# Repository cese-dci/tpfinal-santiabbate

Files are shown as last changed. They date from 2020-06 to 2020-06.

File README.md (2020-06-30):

# TP final de la materia Diseño de Circuitos Impresos - CESE - 2020A
## Réplica  modificada Heltec Wifi LoRA V2

Propuesta general: Eliminar el display OLED y reemplazar los circuitos integrados ESP32 y SX1278 por los módulos ESP32-WROOM y Ra-01.

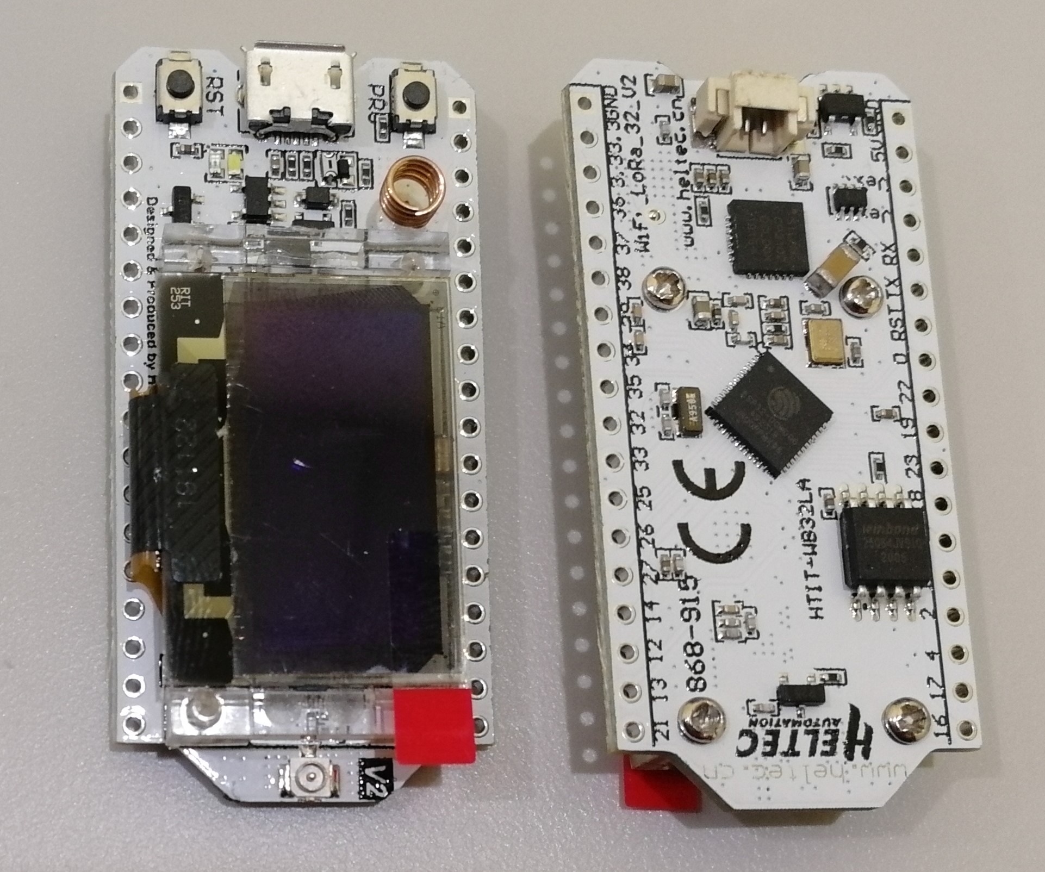
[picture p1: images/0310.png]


## Resultado

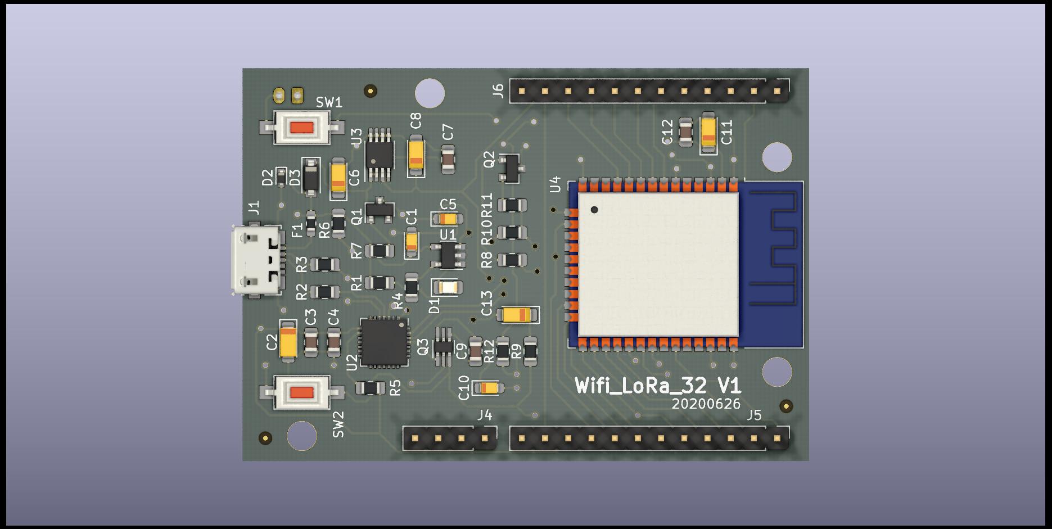
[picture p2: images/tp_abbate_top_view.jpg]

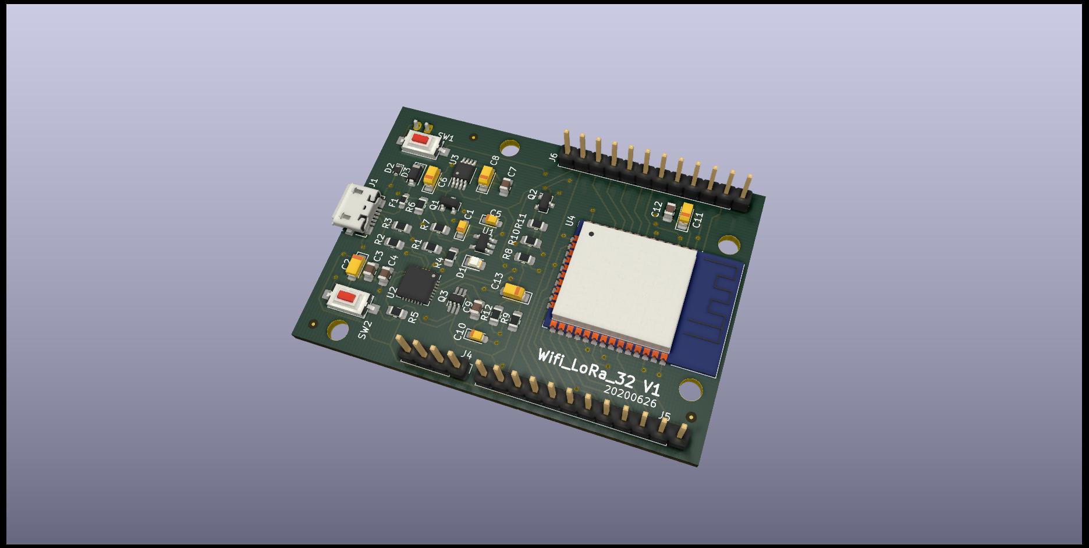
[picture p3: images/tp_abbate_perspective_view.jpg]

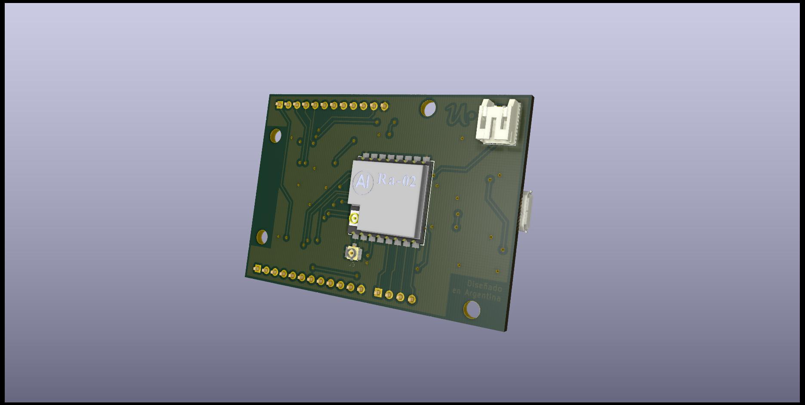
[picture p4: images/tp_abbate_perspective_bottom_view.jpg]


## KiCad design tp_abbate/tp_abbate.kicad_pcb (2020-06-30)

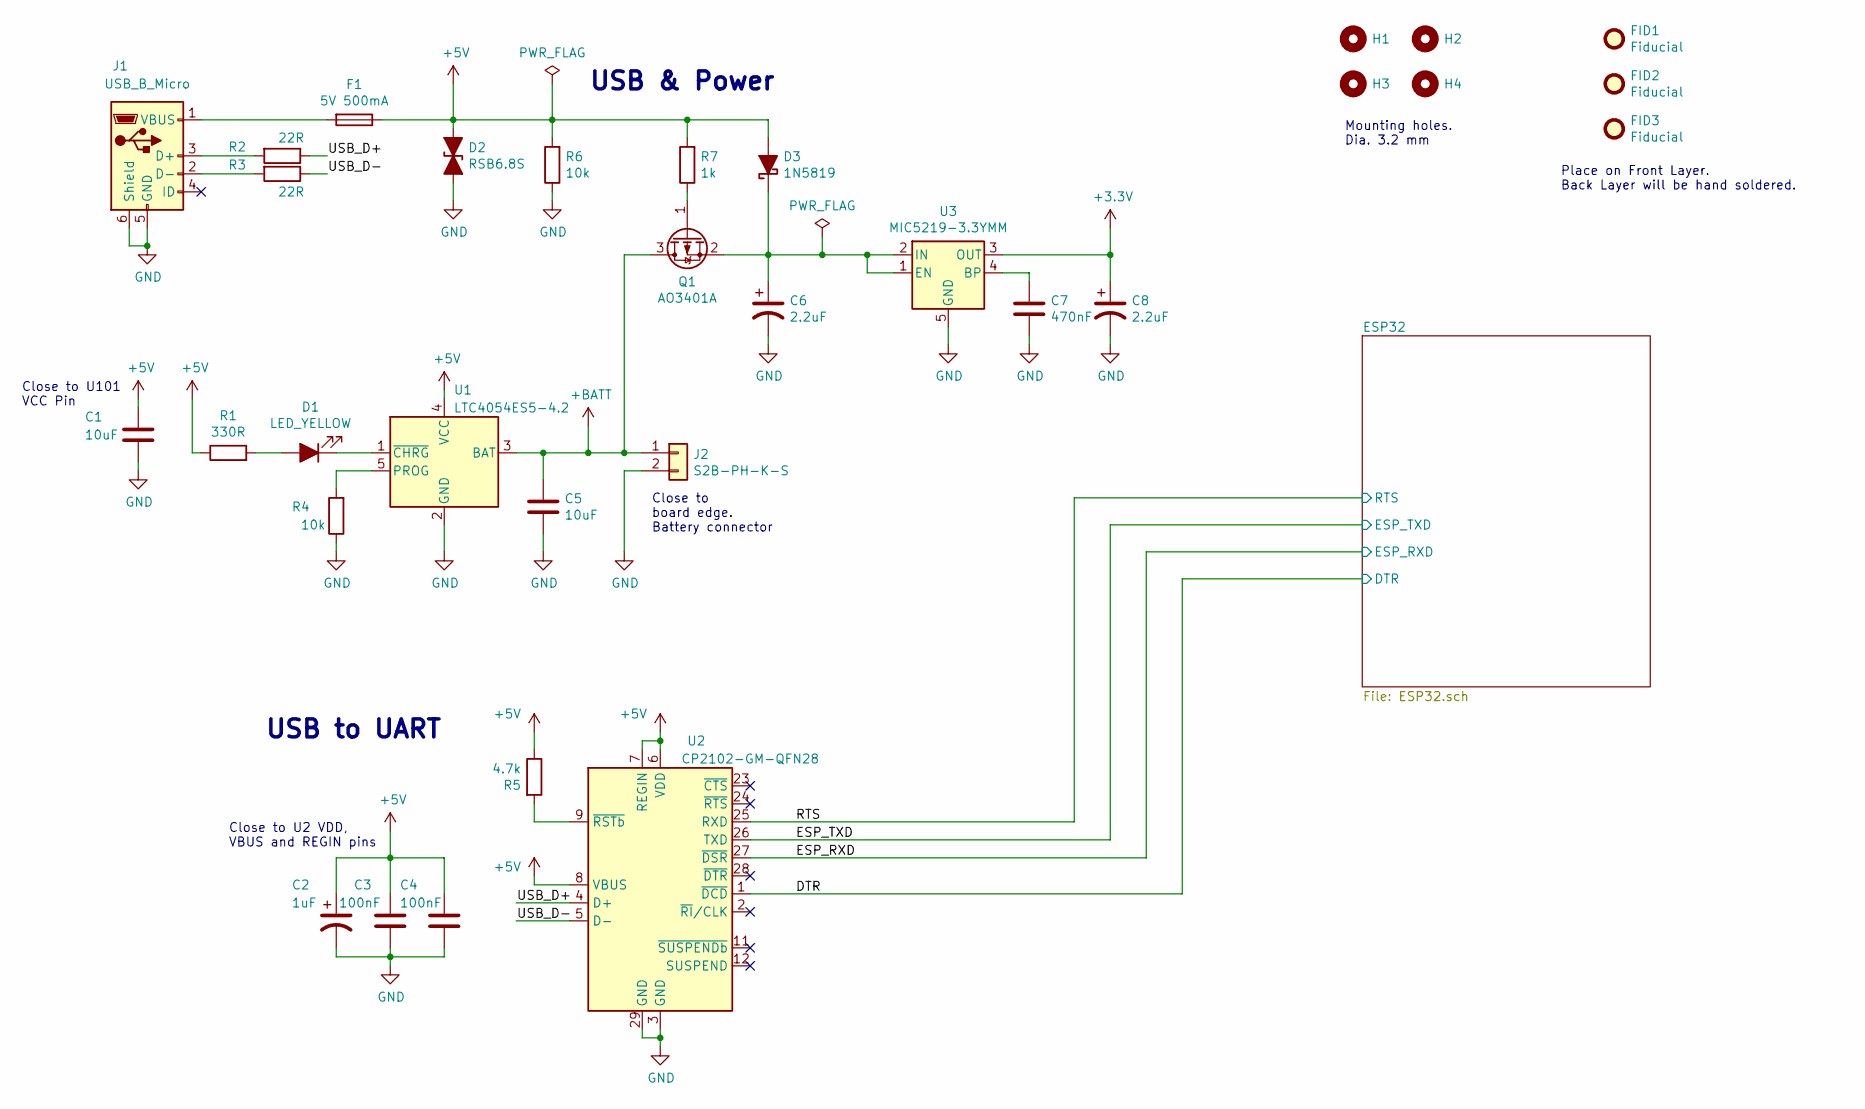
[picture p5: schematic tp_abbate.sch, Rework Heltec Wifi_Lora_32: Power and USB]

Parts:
C1, C5: 10uF; CP_EIA-2012-12_Kemet-R_Pad1.30x1.05mm_HandSolder; Digikey# 478-F981C106MSUAJ6CT-ND
C2: 1uF; CP_EIA-3216-10_Kemet-I_Pad1.58x1.35mm_HandSolder; Digikey# 511-TCA1E105M8RCT-ND
C3, C4: 100nF; C_0805_2012Metric_Pad1.15x1.40mm_HandSolder; Digikey# 399-1177-1-ND
C6, C8: 2.2uF; CP_EIA-3216-18_Kemet-A_Pad1.58x1.35mm_HandSolder; Digikey# TAJA225M010SNJ
C7: 470nF; C_0805_2012Metric_Pad1.15x1.40mm_HandSolder; Digikey# 311-4355-1-ND
D1: LED_YELLOW; LED_0805_2012Metric_Pad1.15x1.40mm_HandSolder
D2: RSB6.8S; D_SOD-523; Digikey# RSB6.8STE61TR-ND
D3: 1N5819; D_SOD-123; Digikey# 1N5819HW-FDICT-ND
F1: 5V 500mA; Fuse_0603_1608Metric_Pad1.05x0.95mm_HandSolder; Digikey# F12131CT-ND
FID1, FID2, FID3: Fiducial; Fiducial_0.5mm_Mask1.5mm
H1, H2, H3, H4: MountingHole; MountingHole_1.8mm_M3
J1: USB_B_Micro; USB_Micro-B_Molex_47346-0001; Digikey# WM17141CT-ND
J2: S2B-PH-K-S; JST_PH_S2B-PH-K_1x02_P2.00mm_Horizontal; Digikey# 455-1719-ND
Q1: AO3401A; SOT-23; Digikey# 785-1001-6-ND
R1: 330R; R_0805_2012Metric_Pad1.15x1.40mm_HandSolder
R2, R3: 22R; R_0805_2012Metric_Pad1.15x1.40mm_HandSolder
R4, R6: 10k; R_0805_2012Metric_Pad1.15x1.40mm_HandSolder
R5: 4.7k; R_0805_2012Metric_Pad1.15x1.40mm_HandSolder
R7: 1k; R_0805_2012Metric_Pad1.15x1.40mm_HandSolder
U1: LTC4054ES5-4.2; TSOT-23-5; Digikey# LTC4054ES5-4.2#TRMPBFTR-ND
U2: CP2102-GM-QFN28; QFN-28-1EP_5x5mm_P0.5mm_EP3.35x3.35mm; Digikey# 336-5890-2-ND
U3: MIC5219-3.3YMM; MSOP-8_3x3mm_P0.65mm; Digikey# MIC5219-3.3YMM-TR-ND

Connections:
+3V3: C8.1, U3.3 (OUT); also elsewhere on the board
+5V: C1.1, C2.1, C3.2, C4.1, D2.1 (A1), D3.2 (A), F1.1, R1.1, R5.1, R6.2, R7.2, U1.4 (VCC), U2.6 (VDD), U2.7 (REGIN), U2.8 (VBUS); also elsewhere on the board
+BATT: C5.1, J2.1, Q1.3 (D), U1.3 (BAT); also elsewhere on the board
/DTR: U2.1 (~DCD); also elsewhere on the board
/ESP_RXD: U2.27 (~DSR); also elsewhere on the board
/ESP_TXD: U2.26 (TXD); also elsewhere on the board
/RTS: U2.25 (RXD); also elsewhere on the board
/USB_D+: R2.1, U2.4 (D+)
/USB_D-: R3.1, U2.5 (D-)
GND: C1.2, C2.2, C3.1, C4.2, C5.2, C6.2, C7.2, C8.2, D2.2 (A2), J1.5 (GND), J1.6 (Shield), J2.2, R4.1, R6.1, U1.2 (GND), U2.3 (GND), U2.29 (GND), U3.5 (GND), U3.6 (GND), U3.7 (GND), U3.8 (GND); also elsewhere on the board
unnamed: C6.1, D3.1 (K), Q1.2 (S), U3.1 (EN), U3.2 (IN)
unnamed: C7.1, U3.4 (BP)
unnamed: D1.1 (K), U1.1 (~CHRG)
unnamed: D1.2 (A), R1.2
unnamed: F1.2, J1.1 (VBUS)
unnamed: J1.2 (D-), R3.2
unnamed: J1.3 (D+), R2.2
unnamed: Q1.1 (G), R7.1
unnamed: R4.2, U1.5 (PROG)
unnamed: R5.2, U2.9 (~RSTb)

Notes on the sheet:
Close to board edge. Battery connector
USB to UART
USB & Power
Close to U101 VCC Pin
Close to U2 VDD, VBUS and REGIN pins
Place on Front Layer. Back Layer will be hand soldered.
Mounting holes. Dia. 3.2 mm

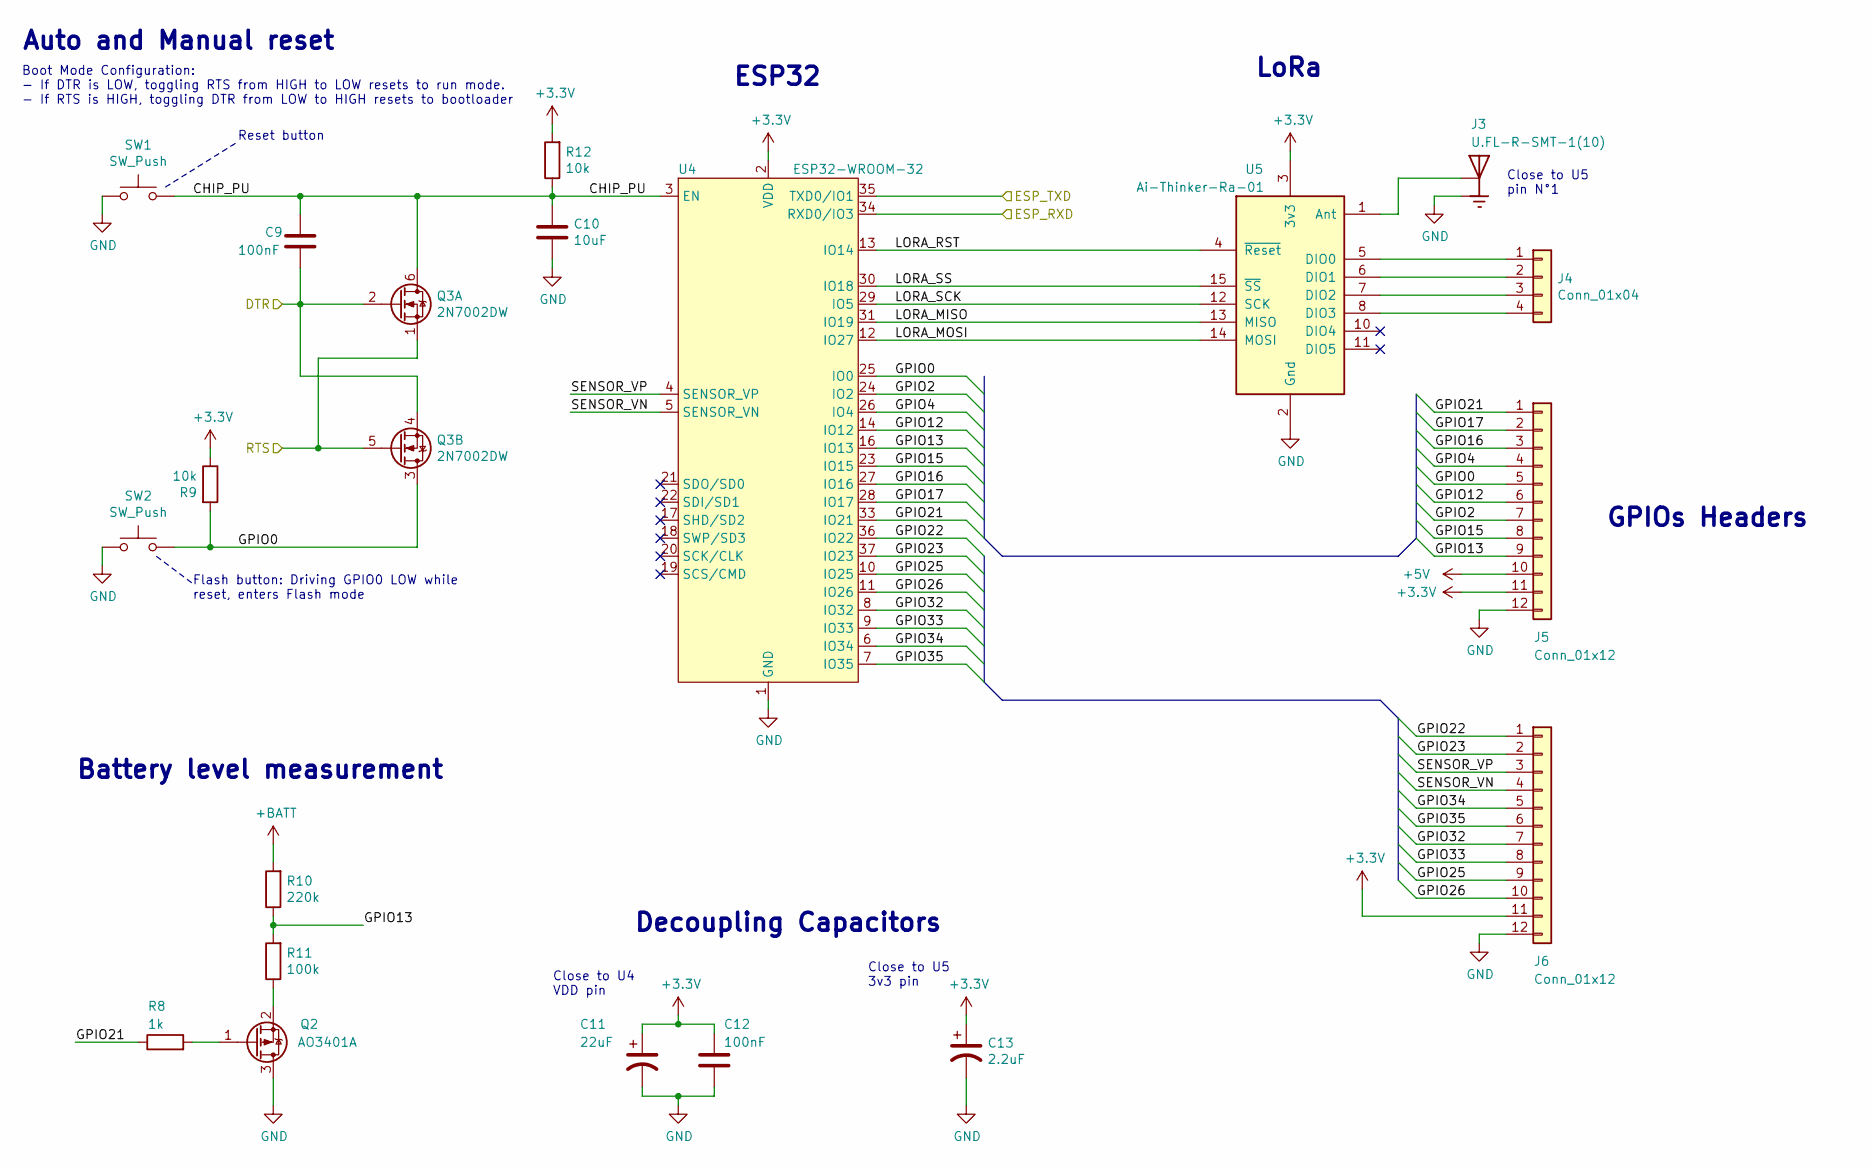
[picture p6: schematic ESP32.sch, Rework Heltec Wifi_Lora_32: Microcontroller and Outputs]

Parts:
C9, C12: 100nF; C_0805_2012Metric_Pad1.15x1.40mm_HandSolder; Digikey# 399-1177-1-ND
C10: 10uF; CP_EIA-2012-12_Kemet-R_Pad1.30x1.05mm_HandSolder; Digikey# 478-F981C106MSUAJ6CT-ND
C11: 22uF; CP_EIA-3216-18_Kemet-A_Pad1.58x1.35mm_HandSolder; Digikey# 478-TAJA226K006SNJCT-ND
C13: 2.2uF; CP_EIA-3216-18_Kemet-A_Pad1.58x1.35mm_HandSolder; Digikey# TAJA225M010SNJ
J3: U.FL-R-SMT-1(10); HRS_U.FL-R-SMT-1(10); Digikey# H11891TR-ND
J4: Conn_01x04; PinHeader_1x04_P2.54mm_Vertical
J5, J6: Conn_01x12; PinHeader_1x12_P2.54mm_Vertical
Q2: AO3401A; SOT-23; Digikey# 785-1001-6-ND
Q3: 2N7002DW; SOT-363_SC-70-6_Handsoldering; Digikey# 2N7002DW-FDICT-ND
R8: 1k; R_0805_2012Metric_Pad1.15x1.40mm_HandSolder
R9, R12: 10k; R_0805_2012Metric_Pad1.15x1.40mm_HandSolder
R10: 220k; R_0805_2012Metric_Pad1.15x1.40mm_HandSolder
R11: 100k; R_0805_2012Metric_Pad1.15x1.40mm_HandSolder
SW1, SW2: SW_Push; SW_SPST_CK_RS282G05A3; Digikey# CKN10384CT-ND
U4: ESP32-WROOM-32; Digikey# 1904-1010-1-ND
U5: Ai-Thinker-Ra-01; Ai-Thinker-Ra-01-LoRa

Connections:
+3V3: C11.1, C12.1, C13.1, J5.11, J6.11, R9.1, R12.2, U4.2 (VDD), U5.3 (3v3); also elsewhere on the board
+5V: J5.10; also elsewhere on the board
+BATT: R10.2; also elsewhere on the board
/DTR: C9.2, Q3.2 (G1), Q3.4 (S2); also elsewhere on the board
/ESP32/CHIP_PU: C9.1, C10.1, Q3.6 (D1), R12.1, SW1.2, U4.3 (EN)
/ESP32/GPIO0: J5.5, Q3.3 (D2), R9.2, SW2.2, U4.25 (IO0)
/ESP32/GPIO2: J5.7, U4.24 (IO2)
/ESP32/GPIO4: J5.4, U4.26 (IO4)
/ESP32/GPIO12: J5.6, U4.14 (IO12)
/ESP32/GPIO13: J5.9, R10.1, R11.2, U4.16 (IO13)
/ESP32/GPIO15: J5.8, U4.23 (IO15)
/ESP32/GPIO16: J5.3, U4.27 (IO16)
/ESP32/GPIO17: J5.2, U4.28 (IO17)
/ESP32/GPIO21: J5.1, R8.1, U4.33 (IO21)
/ESP32/GPIO22: J6.1, U4.36 (IO22)
/ESP32/GPIO23: J6.2, U4.37 (IO23)
/ESP32/GPIO25: J6.9, U4.10 (IO25)
/ESP32/GPIO26: J6.10, U4.11 (IO26)
/ESP32/GPIO32: J6.7, U4.8 (IO32)
/ESP32/GPIO33: J6.8, U4.9 (IO33)
/ESP32/GPIO34: J6.5, U4.6 (IO34)
/ESP32/GPIO35: J6.6, U4.7 (IO35)
/ESP32/LORA_MISO: U4.31 (IO19), U5.13 (MISO)
/ESP32/LORA_MOSI: U4.12 (IO27), U5.14 (MOSI)
/ESP32/LORA_RST: U4.13 (IO14), U5.4 (~Reset)
/ESP32/LORA_SCK: U4.29 (IO5), U5.12 (SCK)
/ESP32/LORA_SS: U4.30 (IO18), U5.15 (~SS)
/ESP32/SENSOR_VN: J6.4, U4.5 (SENSOR_VN)
/ESP32/SENSOR_VP: J6.3, U4.4 (SENSOR_VP)
/ESP_RXD: U4.34 (RXD0/IO3); also elsewhere on the board
/ESP_TXD: U4.35 (TXD0/IO1); also elsewhere on the board
/RTS: Q3.1 (S1), Q3.5 (G2); also elsewhere on the board
GND: C10.2, C11.2, C12.2, C13.2, J3.1 (GND), J3.3 (GND), J5.12, J6.12, Q2.3 (D), SW1.1, SW2.1, U4.1 (GND), U4.15 (GND), U4.38 (GND), U4.39 (GND), U5.2 (Gnd), U5.9 (Gnd), U5.16 (Gnd); also elsewhere on the board
unnamed: J3.2 (SIG), U5.1 (Ant)
unnamed: J4.1, U5.5 (DIO0)
unnamed: J4.2, U5.6 (DIO1)
unnamed: J4.3, U5.7 (DIO2)
unnamed: J4.4, U5.8 (DIO3)
unnamed: Q2.1 (G), R8.2
unnamed: Q2.2 (S), R11.1

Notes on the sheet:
ESP32
Close to U4 VDD pin
GPIOs Headers
LoRa
Close to U5 3v3 pin
Flash button: Driving GPIO0 LOW while reset, enters Flash mode
Reset button
Auto and Manual reset
Boot Mode Configuration: - If DTR is LOW, toggling RTS from HIGH to LOW resets to run mode. - If RTS is HIGH, toggling DTR from LOW to HIGH resets to bootloader
Decoupling Capacitors
Battery level measurement
Close to U5 pin N°1

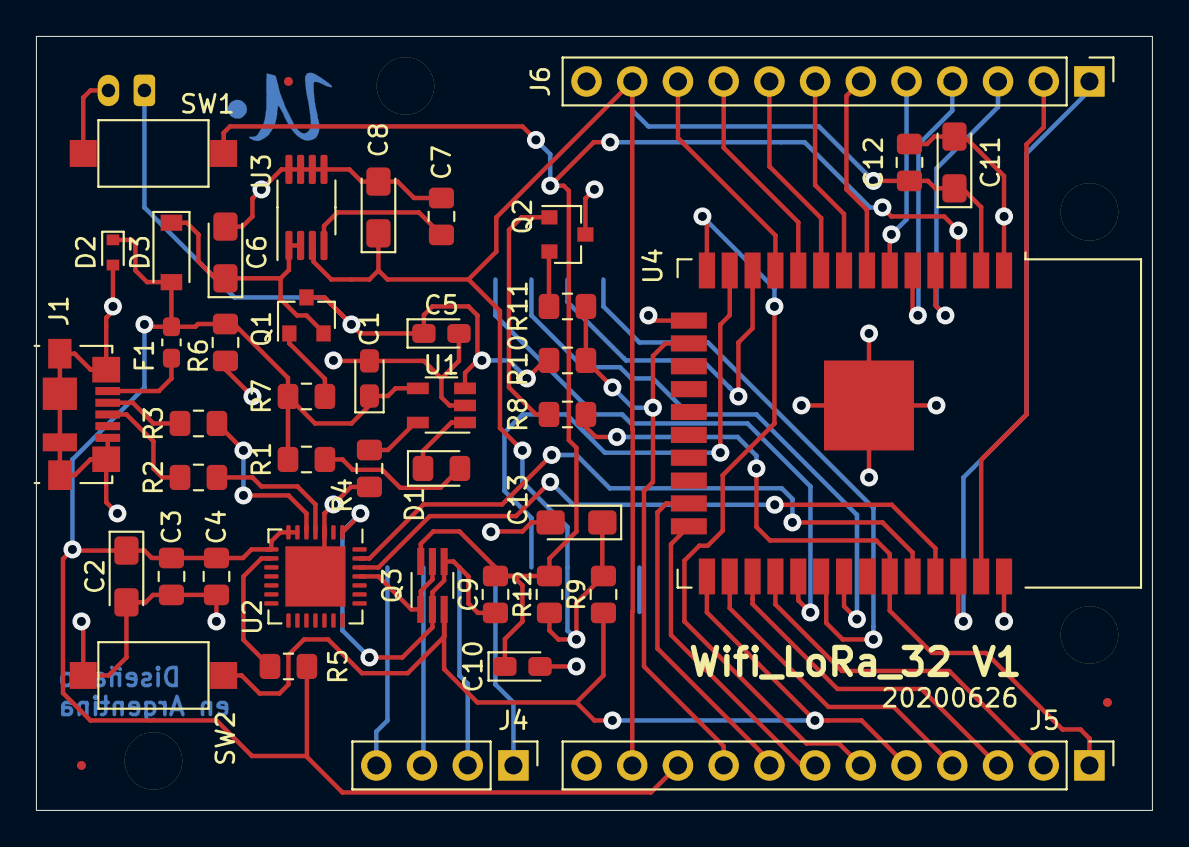
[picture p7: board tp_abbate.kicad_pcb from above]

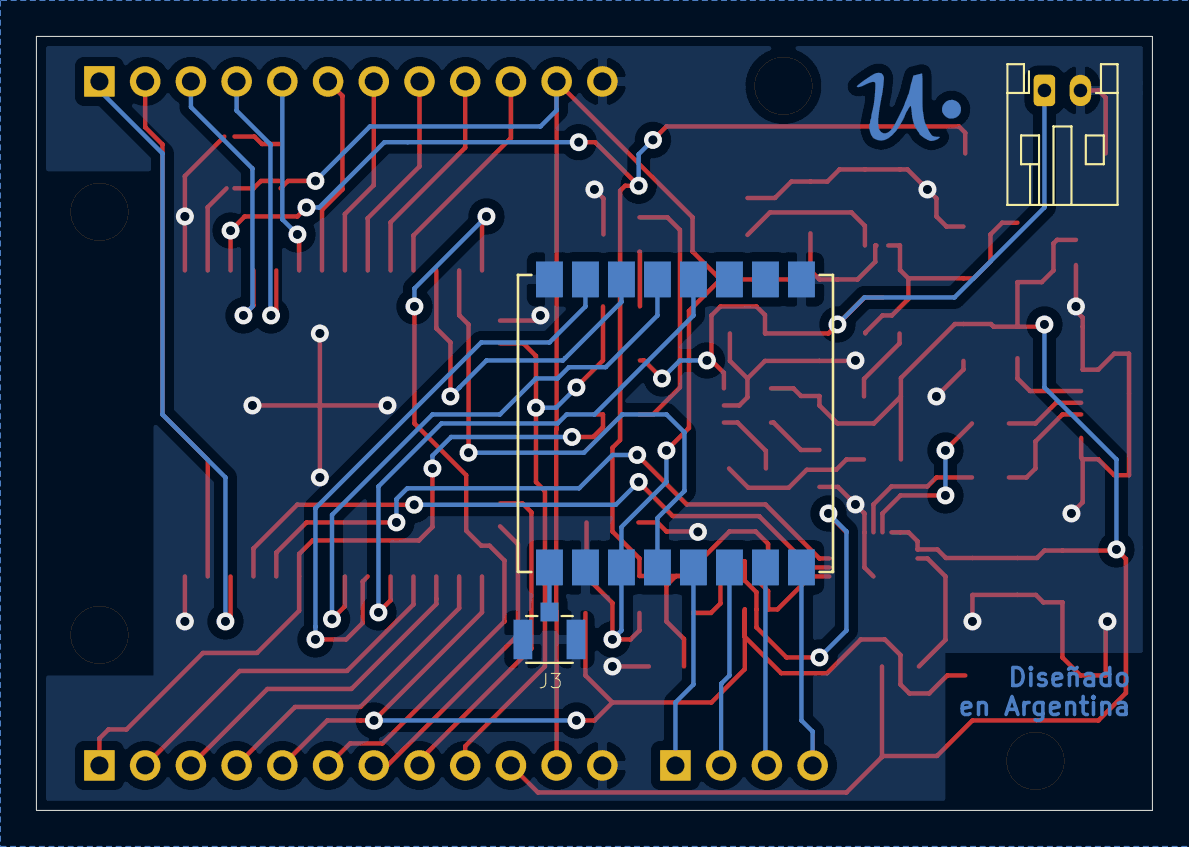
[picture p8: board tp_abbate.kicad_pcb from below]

Board: 2 copper layers, 62.0 x 43.0 mm, 52 parts (3 on the bottom side), 52 nets.

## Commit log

2020-06-09 Commit inicial
    [tp_abbate.kicad_pcb, tp_abbate.sch]
2020-06-09 Fix comentarios compañero
    [tp_abbate.sch]
2020-06-23 Trabajo en PCB - ubicacion de componentes
    [ESP32.sch, tp_abbate.kicad_pcb, tp_abbate.sch]
2020-06-26 WIP revisión PCB
    [ESP32.sch, tp_abbate.kicad_pcb, tp_abbate.sch]
2020-06-26 Subo PCB para revisión compañero
    [ESP32.sch, tp_abbate.kicad_pcb, tp_abbate.sch]
2020-06-27 Corrijo indicaciones de compañero
    [ESP32.sch, tp_abbate.kicad_pcb, tp_abbate.sch]
2020-06-30 Revisión Final - Entrega
    [ESP32.sch, tp_abbate.kicad_pcb, tp_abbate.sch]

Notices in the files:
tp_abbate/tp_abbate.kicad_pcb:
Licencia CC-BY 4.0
